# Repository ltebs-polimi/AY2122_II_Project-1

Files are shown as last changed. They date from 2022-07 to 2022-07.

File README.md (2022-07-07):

# AY2122_II_Project-1

## Pulseoximeter
The project involves the development of a portable pulseoximeter made using CY8CKIT-059 Development Kit by Cypress/Infineon and the MAX30101, a High-Sensitivity Pulse Oximeter and Heart-Rate Sensor for Wearable Health. Exploiting the circular buffer present inside the sensor, it is possible to extract the values coming from Infrared and Red LEDs and feed them inside a peak detection algorithm for PPG analysis, which outputs the SpO2 and Heart Rate values. Such function has been forked by the [MAX30101_Sensor_Library](https://github.com/sparkfun/SparkFun_MAX3010x_Sensor_Library/blob/master/src/spo2_algorithm.cpp) of the manufacturer Maxim Integrated; the function has been modified to our specific case. 
The project also involved the PCB design and production through press-n-print technique, the 3D case design and printing and the overall assembly of the final case.
## GUI
GUI_screenshot
On the GUI it is also possible to make instant changes to the registers, which directly influence the MAX30101, such as the ADC range, the LED pulse width of the two LEDs, the LEDs pulse amplitude and the Sample Rate. These values will change the Full Scale Range of the readings, as well as the SNR (signal-to-noise-ratio).
## Final assembled device
The final device resembles a commercial pulseoximeter with a rudimental hinge that secures the finger in place over the photodiode, so that a constant pressure is applied. Moreover an internal coating was applied in order not to let light pass, so to assure a reliable sensor measure.


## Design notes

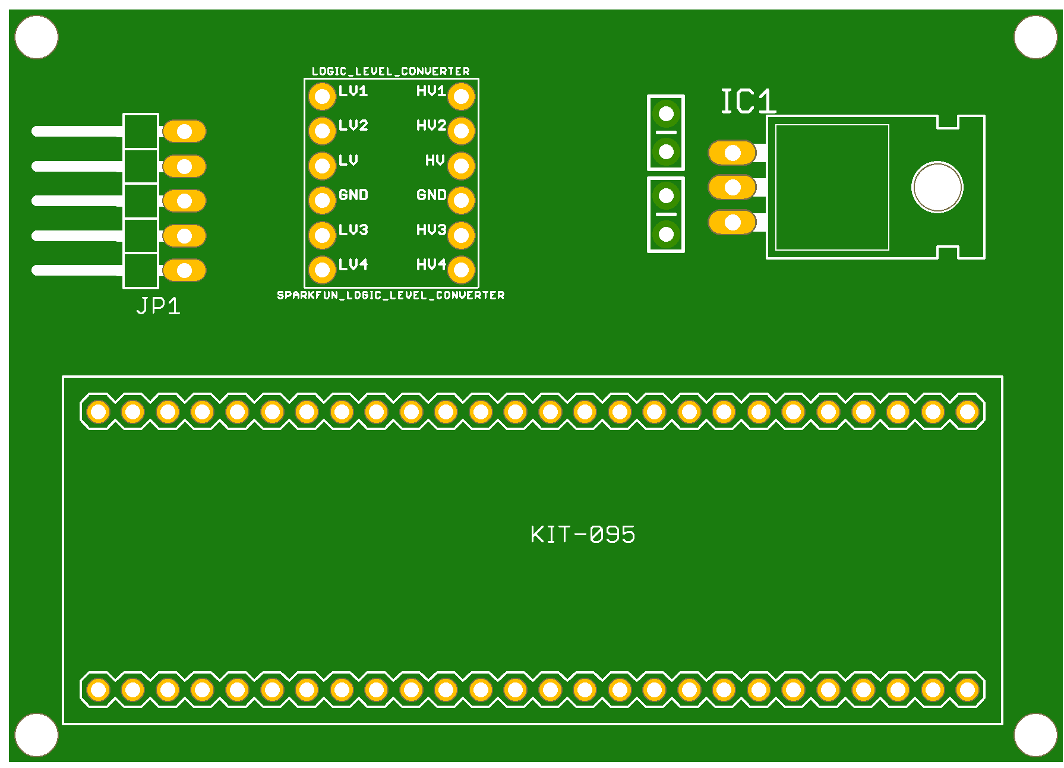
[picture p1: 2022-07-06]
EAGLE/MAX30101_Eagle/MAX30101_Qwiic_PCB_v6_top.png

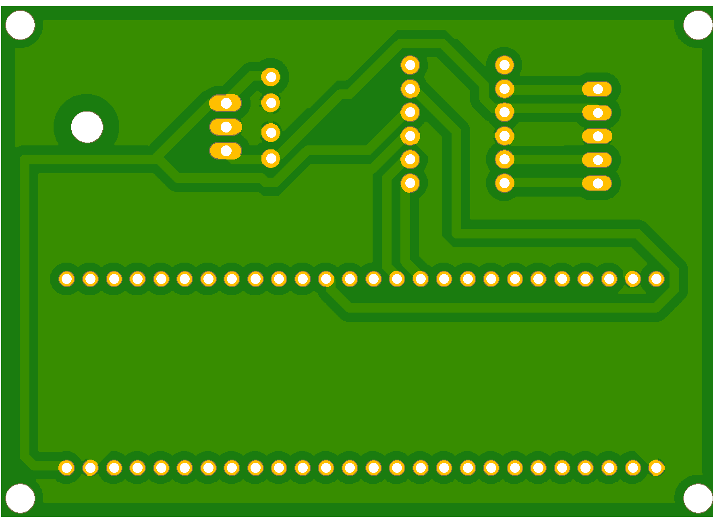
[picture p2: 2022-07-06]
EAGLE/MAX30101_Eagle/MAX30101_Qwiic_PCB_v6_bottom.png

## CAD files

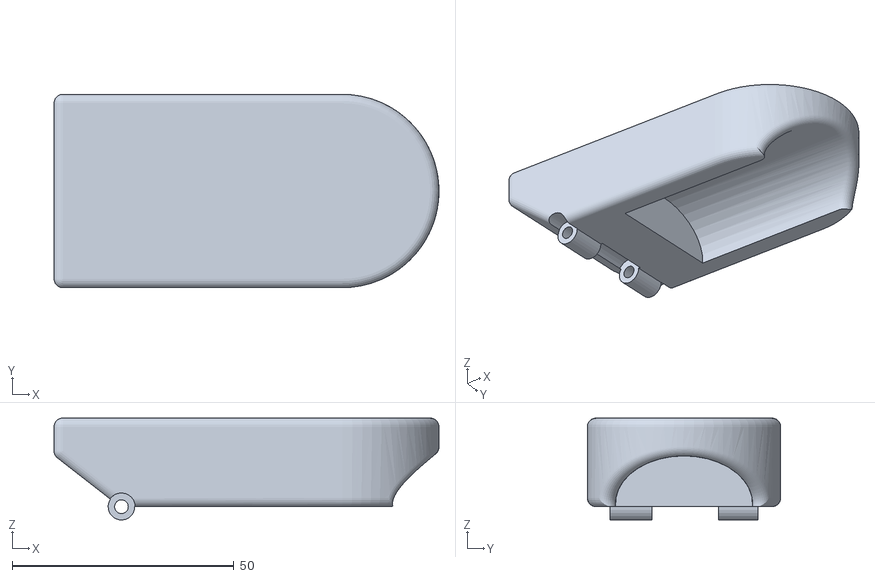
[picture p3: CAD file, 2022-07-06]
3Dcase/3Dcase_up.STL
86.8 x 43.6 x 23.0

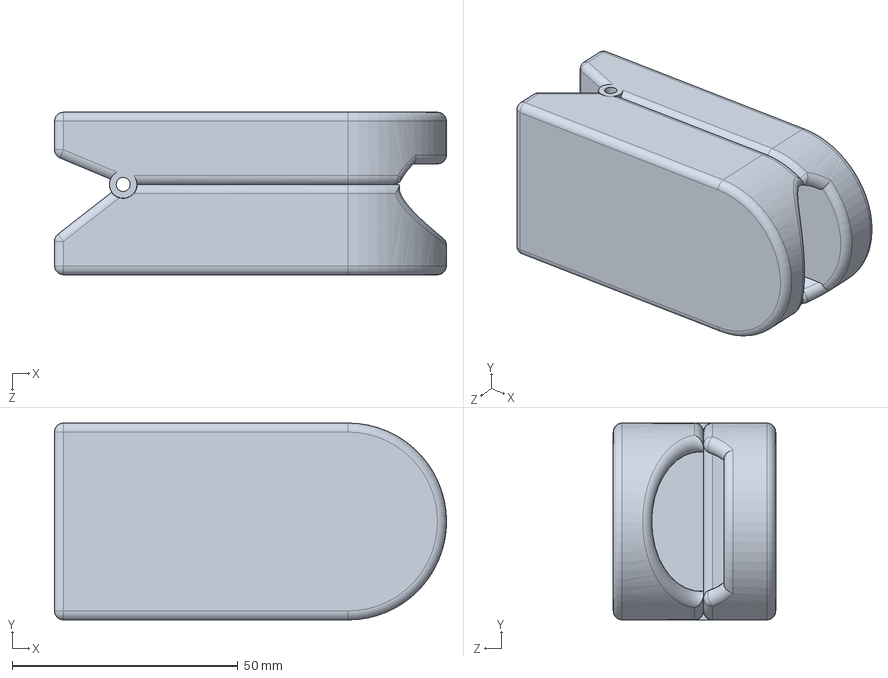
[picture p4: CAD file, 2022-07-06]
3Dcase/3Dcase.SLDPRT
86.8 x 43.6 x 36.0 mm

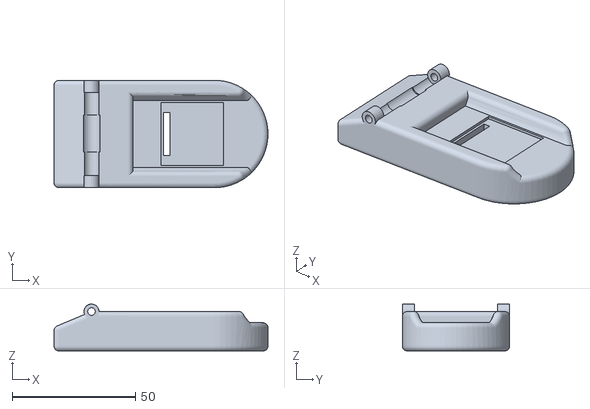
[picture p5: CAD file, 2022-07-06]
3Dcase/3Dcase_down.STL
86.8 x 43.6 x 19.0

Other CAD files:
3Dcase/3Dcase.STL

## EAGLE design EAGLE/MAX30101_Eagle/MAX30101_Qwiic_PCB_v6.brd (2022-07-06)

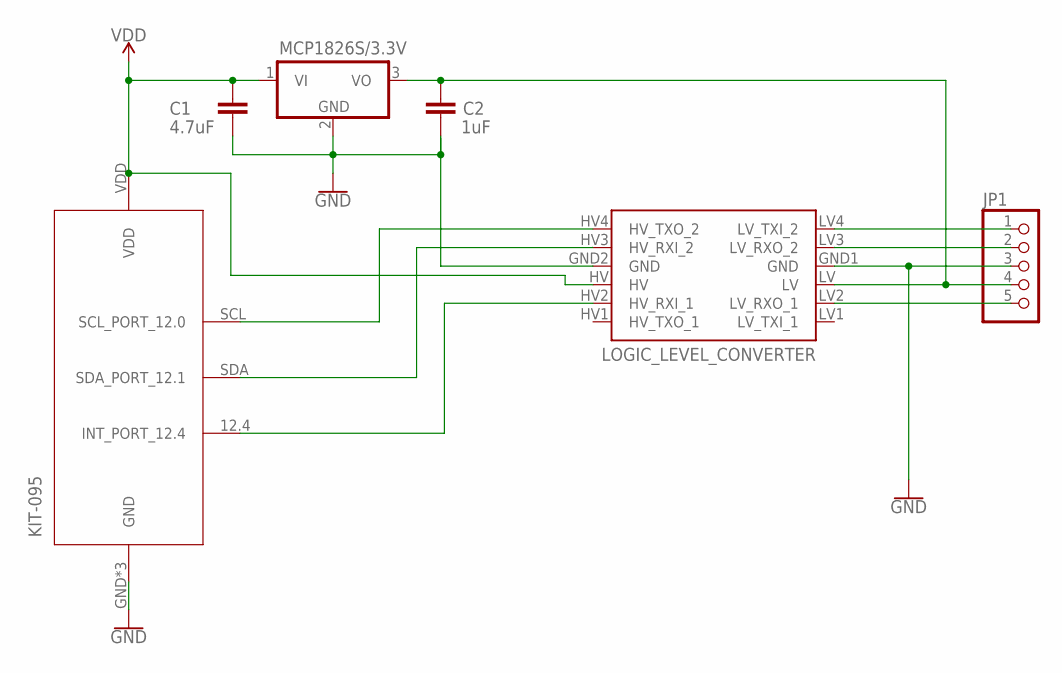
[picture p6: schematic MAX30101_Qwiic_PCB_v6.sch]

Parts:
C1: 4.7uF; CAP-PTH-SMALL-KIT
C2: 1uF; CAP-PTH-SMALL-KIT
IC1: 7805T; TO220H
JP1: PINHD-1X5/90; 1X05/90
KIT-095: KIT-095
LOGIC_LEVEL_CONVERTER: SPARKFUN_LOGIC_LEVEL_CONVERTER

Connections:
GND: C1.2, C2.2, IC1.2 (GND), JP1.3, KIT-095.GND, KIT-095.GND_ (GND), KIT-095._GND (GND), LOGIC_LEVEL_CONVERTER.GND1 (GND), LOGIC_LEVEL_CONVERTER.GND2 (GND)
unnamed: C2.1, IC1.3 (VO), JP1.4, LOGIC_LEVEL_CONVERTER.LV
unnamed: KIT-095.SCL (SCL_PORT_12.0), LOGIC_LEVEL_CONVERTER.HV4 (HV_TXO_2)
unnamed: KIT-095.SDA (SDA_PORT_12.1), LOGIC_LEVEL_CONVERTER.HV3 (HV_RXI_2)
unnamed: KIT-095.12.4 (INT_PORT_12.4), LOGIC_LEVEL_CONVERTER.HV2 (HV_RXI_1)
unnamed: JP1.1, LOGIC_LEVEL_CONVERTER.LV4 (LV_TXI_2)
unnamed: JP1.2, LOGIC_LEVEL_CONVERTER.LV3 (LV_RXO_2)
unnamed: JP1.5, LOGIC_LEVEL_CONVERTER.LV2 (LV_RXO_1)
VDD: C1.1, IC1.1 (VI), KIT-095.VDD, LOGIC_LEVEL_CONVERTER.HV

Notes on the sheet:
MCP1826S/3.3V

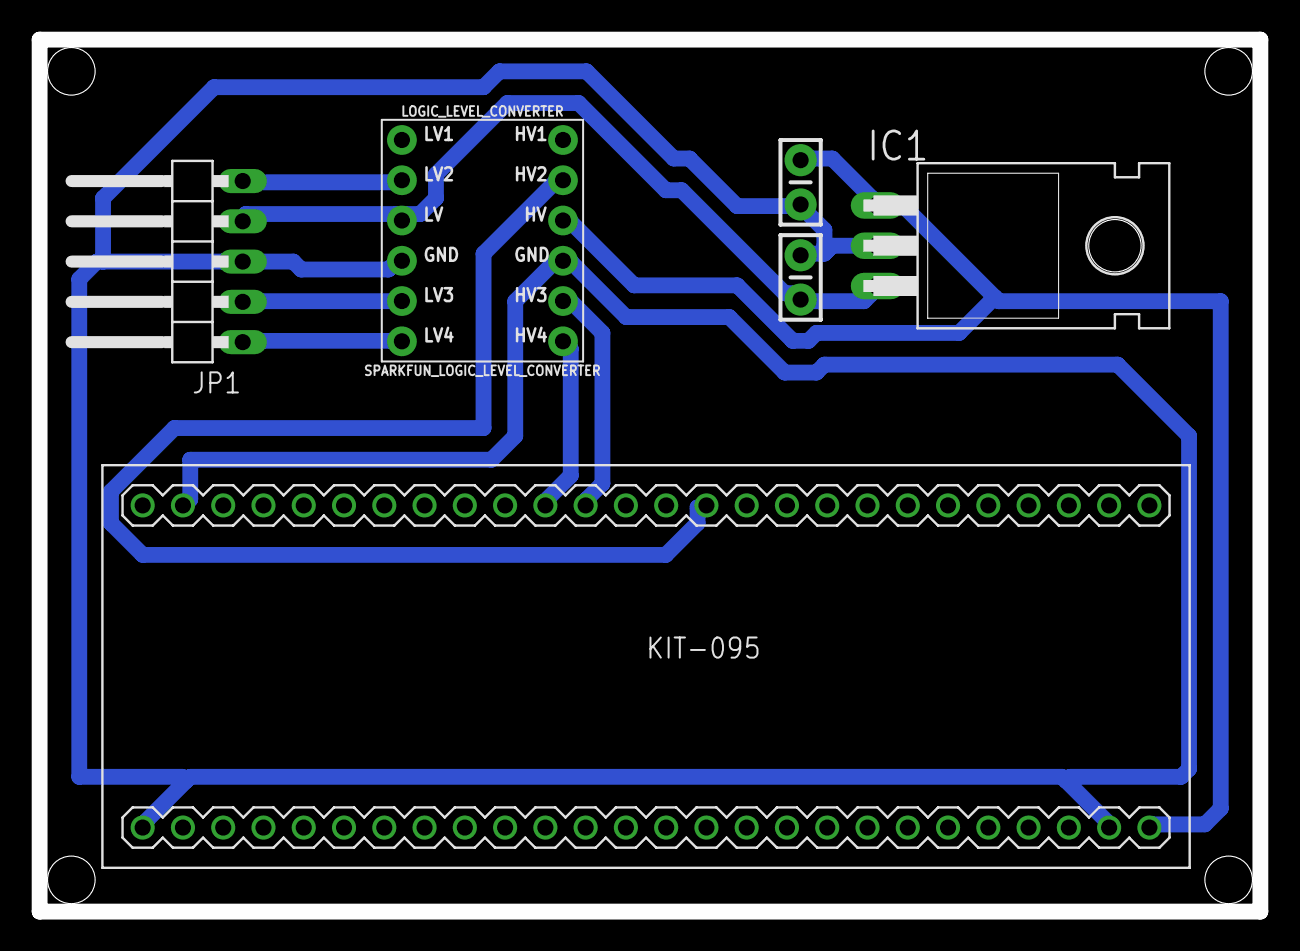
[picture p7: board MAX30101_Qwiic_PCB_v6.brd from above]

Board: 2 copper layers, 77.0 x 55.0 mm, 6 parts (0 on the bottom side), 9 nets.

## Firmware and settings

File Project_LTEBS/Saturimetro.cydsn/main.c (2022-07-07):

/*
    LAB PROJECT 2022, Group 1
    Emanuele Falli
    Federico Monterosso
    Francesca Terranova
*/

#include "project.h"
#include "MAX30101.h"
#include "stdio.h"
#include "I2C_Interface.h"
#include "SpO2_HR.h"
#include "Timer.h"
#include "isr.h"
#include "USER.h"
#include "setting_parameters.h"

#define UART_DEBUG
#define FIFO_max_size 25 
/*25 has been set as the maximum size so that half a second is measured every
time the interrupt is triggere by the filling of the FIFO*/

#ifdef UART_DEBUG
    
    #define DEBUG_TEST 1
    
#else
    
    #define DEBUG_TEST 0
    
#endif

#define debug_print(msg) do { if (DEBUG_TEST) UART_Debug_PutString(msg);} while (0)

CY_ISR_PROTO(MAX30101_ISR);

uint8_t flag_temp = 0; 
/*flag_temp is activated inside the isr code of the MAX30101 and ensures that the sampling frequency of 
the main code is executed at the desired frequency equal to that of the filling of the FIFO*/

uint8_t j=0; 
/*this flag controls the number of samples before reaching the 200 samples 
(4 seconds of measurement at a sample rate of 50 Sa/s) that trigger the actuation of the maxim function 
for spo2 and hr calculation*/
uint8 flag_start = 1;


int main(void)
{
    // Variables
    MAX30101_Data data;
    data.head = 0;
    data.tail = 0;
    char msg[50];
    uint8_t active_leds = 2;
    uint8_t rp, wp, flag = 0;
    int32_t spo2; //SPO2 value calculated through the maxim function given by the manufacturer
    int8_t validSPO2; //indicator to show if the SPO2 calculation is valid
    int32_t heartRate; //heart rate value 
    int8_t validHeartRate; //indicator to show if the heart rate calculation is valid
    uint32_t irBuffer[200]; //infrared LED sensor data
    uint32_t redBuffer[200];  //red LED sensor data
    int32_t bufferLength = 200;
    int32_t somma=0; 
    int32_t avg_hr=0;
    int num_samples;
 
    int i=0;
    int f=1;
    
    // Initialization
    MAX30101_Start();
    UART_Debug_Start();
    CyDelay(100);    
    if (MAX30101_IsDevicePresent() == MAX30101_OK)
    {
        // Check if device is present
        Connection_LED_Write(1);
        
        // Soft reset sensor
        MAX30101_Reset();
        CyDelay(100);
       
        // Wake up sensor
        MAX30101_WakeUp();       
        // Only the FIFO_AFULL interrupt is activated, therefore the isr code works only in this case.
        MAX30101_EnableFIFOAFullInt();
     
        // set 25 samples to trigger interrupt
        MAX30101_SetFIFOAlmostFull(FIFO_max_size);

        // enable fifo rollover
        MAX30101_EnableFIFORollover();
        
        // samples averaged       
        MAX30101_SetSampleAverage(MAX30101_SAMPLE_AVG_2);
        // Set LED Power level
        MAX30101_SetLEDPulseAmplitude(MAX30101_LED_1, 0x1F);        
        MAX30101_SetLEDPulseAmplitude(MAX30101_LED_2, 0x1F);
               
        // Set ADC Range
        MAX30101_SetSpO2ADCRange(MAX30101_ADC_RANGE_8192);
        
        // Pulse width
        MAX30101_SetSpO2PulseWidth(MAX30101_PULSEWIDTH_411);
        
        /* Set Sample Rate, in a way to ensure that 50 Sa/s is always kept constant, therefore the 
        sample average needs to be configured properly when changing the sample rate through the GUI*/ 
        MAX30101_SetSpO2SampleRate(MAX30101_SAMPLE_RATE_100);
        
        // Set mode (always spo2 mode in this project)
        MAX30101_SetMode(MAX30101_SPO2_MODE);
        
        // Enable Slots
        MAX30101_DisableSlots();
        
    }
    
    isr_MAX30101_StartEx(MAX30101_ISR);
    isr_RX_StartEx(Custom_ISR_RX);
    
    // Clear FIFO
    MAX30101_ClearFIFO();
    
    CyGlobalIntEnable; /* Enable global interrupts. */
      
    for(;;)
    {    
        if(flag_temp == 1)
        /*this flag is controlled by the isr of the MAX (issued only by the filling of the FIFO because
        the other interrupts are all disabled*/
        {
            MAX30101_IsFIFOAFull(&flag);
            if(flag>0)
            {
                MAX30101_ReadReadPointer(&rp);
                MAX30101_ReadWritePointer(&wp);
                //Calculate the number of readings we need to get from sensor (always 25 in this case)
                num_samples = wp - rp;
                if (num_samples <= 0) num_samples += 32; //Wrap condition                
                // Read FIFO
                MAX30101_ReadFIFO(num_samples, active_leds, &data);
                for (i=0;i<num_samples;i++)
                {                    
                    //the 25 samples are stored separately inside two buffers of length 200
                    redBuffer[j] = data.red[data.tail+i];
                    irBuffer[j] = data.IR[data.tail+i];
                    j++;
                    debug_print("1,");
                    /*these numbers help us in intercepting the right value inside the python code,
                    so that they are placed in the corresponding array accordingly and are displayed
                    inside the plot or saved in the labels of Spo2 and HR*/
                    sprintf(msg, "%ld,", data.IR[data.tail+i]);
                    debug_print(msg);
                    debug_print("2,");
                    sprintf(msg, "%ld,", data.red[data.tail+i]);
                    debug_print(msg);
                    
                    if(j<bufferLength)
                    {
                        /*these null values ensure that the array length sent via UART to the GUI 
                        is always constant; in this way when, after the iterations, we obtain a measure
                        of Spo2 and HR, we can save them appropriately.*/
                        debug_print("0,");
                        debug_print("0,");
                        debug_print("0,");
                        debug_print("0\n");
                    }
                }
                
                if(j>=bufferLength) 
                {
                    //we have reached 200 samples and the maxim function is triggered
                    maxim_heart_rate_and_oxygen_saturation(irBuffer, bufferLength, redBuffer, &spo2, &validSPO2, &heartRate, &validHeartRate);
                    j=bufferLength - 50;
                    /*50 samples are deleted, and replaced with a new second of measurement
                    coming from the sensor*/
                    for (int i=50; i<bufferLength; i++) 
                    {
                        /*The remaining 150 samples are shifter up at the beginning of the array so 
                        that the last second is entered at the end and the appropriate sequence is kept.*/
                        redBuffer[i-50] = redBuffer[i];
                        irBuffer[i-50] = irBuffer[i];
                    }
                    /*the spo2 and HR values are generated and will replace the empty values shown before,
                    to be sent via UART to the GUI*/
                    debug_print("3,");
                    sprintf(msg, "%ld,", spo2);
                    debug_print(msg);
                    debug_print("4,");
                    sprintf(msg, "%ld\n", avg_hr);
                    debug_print(msg);
                    if(heartRate > 60 && heartRate < 120) 
                    {
                        //an average of 10 values of HR is performed to obtain a more constant value
                        somma += heartRate;
                        if(f==10)
                        {
                            somma = somma/10;
                            f = 0;
                            avg_hr = somma;
                            somma = 0;
                        }
                        f++;
                    }
                }
            }
            
            if(flag_ADC == 1)
            {
                /*this series of flags represent each parameter that can be changed via the GUI, each
                flag is activated when changing a specific parameter and the setting parameters function
                is performed.*/
                if(flag_start)
                {
                    /*the flag_start is activated the first time the code is run, after the user activates a changing of a
                    parameter inside the GUI; it is done in a way to ensure that all the other parameters not changed
                    are still initialized to a default variable, otherwise the program would not function anymore.*/
                    Pulse_amp = 0x1F;
                    Pulse_width = MAX30101_PULSEWIDTH_411;
                    Samples = MAX30101_SAMPLE_RATE_100;
                    Average = MAX30101_SAMPLE_AVG_2;
                    flag_start = 0;
                }
                setting_parameters(ADC_range, Pulse_width, Pulse_amp, Samples, Average);
                flag_ADC = 0;
                
            }
            
            if(flag_PW == 1)
            {
                if(flag_start)
                {
                    Pulse_amp = 0x1F;
                    Samples = MAX30101_SAMPLE_RATE_100;
                    Average = MAX30101_SAMPLE_AVG_2;
                    ADC_range = MAX30101_ADC_RANGE_4096;
                    flag_start = 0;
                }
                setting_parameters(ADC_range, Pulse_width,  Pulse_amp, Samples, Average);
                flag_PW = 0;
            }
            
            if(flag_PA == 1)
            {
                if(flag_start)
                {
                    Pulse_width = MAX30101_PULSEWIDTH_411;
                    Samples = MAX30101_SAMPLE_RATE_100;
                    Average = MAX30101_SAMPLE_AVG_2;
                    ADC_range = MAX30101_ADC_RANGE_4096;
                    flag_start = 0;
                }
                setting_parameters(ADC_range, Pulse_width,  Pulse_amp, Samples, Average);
                flag_PA = 0;
            }
            
            if(flag_SR == 1)
            {
                if(flag_start)
                {
                    Pulse_width = MAX30101_PULSEWIDTH_411;
                    Pulse_amp = 0x1F;
                    ADC_range = MAX30101_ADC_RANGE_4096;
                    flag_start = 0;
                }
                setting_parameters(ADC_range, Pulse_width,  Pulse_amp, Samples, Average);
                flag_SR = 0;
            }
            flag_temp = 0;
        }        
    } 
}   


CY_ISR(MAX30101_ISR)
{
    flag_temp = 1;
    Connection_LED_Write(!Connection_LED_Read());
    MAX30101_INT_ClearInterrupt();
}

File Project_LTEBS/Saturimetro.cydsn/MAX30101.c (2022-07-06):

/**
*   Source file for the MAX30101 library.
*/

#include "I2C_Interface.h"
#include "I2C_Master.h"
#include "MAX30101.h"
#include "string.h"
#include "stdio.h"
#include "project.h"
#include "isr.h"

//==============================================
//          MACROS
//==============================================

/**
*   \brief Mask for Power Ready interrupt.
*/
#define MAX30101_INT_PWR_RDY_MASK   0xFE

/**
*   \brief Mask for FIFO A FULL interrupt.
*/
#define MAX30101_INT_FIFO_A_FULL_MASK   0x7F

/**
*   \brief Enable FIFO A FULL interrupt.
*/
#define MAX30101_INT_FIFO_A_FULL_ENABLE 0x80

/**
*   \brief Disable FIFO A FULL interrupt.
*/
#define MAX30101_INT_FIFO_A_FULL_DISABLE 0x00

/**
*   \brief Mask for PPG ready interrupt.
*/
#define MAX30101_INT_PPG_RDY_MASK     0xBF

/**
*   \brief Enable PPG ready interrupt.
*/
#define MAX30101_INT_PPG_RDY_ENABLE 0x40

/**
*   \brief Disable PPG ready interrupt.
*/
#define MAX30101_INT_PPG_RDY_DISABLE 0x00

/**
*   \brief Mask for FIFO overflow interrupt.
*/
#define MAX30101_INT_ALC_OVF_MASK     0xDF

/**
*   \brief Enable OVERFLOW interrupt.
*/
#define MAX30101_INT_ALC_OVF_ENABLE 0x20

/**
*   \brief Disable OVERFLOW interrupt.
*/
#define MAX30101_INT_ALC_OVF_DISABLE 0x00

/**
*   \brief Mask for temperature data ready interrupt.
*/
#define MAX30101_INT_TMP_RDY_MASK     0xFD

/**
*   \brief Enable temperature ready interrupt.
*/
#define MAX30101_INT_TMP_RDY_ENABLE 0x02

/**
*   \brief Disable temperature ready interrupt.
*/
#define MAX30101_INT_TMP_RDY_DISABLE 0x00

/**
*   \brief Mask for sample average settings.
*/
#define MAX30101_SMP_AVG_MASK    0x1F

/**
*   \brief Mask for fifo rollover.
*/
#define MAX30101_FIFO_ROLLOVER_MASK    0xEF

/**
*   \brief Mask for sample average settings.
*/
#define MAX30101_FIFO_ROLLOVER_ENABLE    0x10

/**
*   \brief Mask for sample average settings.
*/
#define MAX30101_FIFO_ROLLOVER_DISABLE    0x00

/**
*   \brief Mask for FIFO A Full samples.
*/
#define MAX30101_FIFO_A_FULL_MASK   0xF0

/**
*   \brief Mask for shutdown bit.
*/
#define MAX30101_SHUTDOWN_MASK 0x7F

/**
*   \brief Enable shutdown
*/
#define MAX30101_SHUTDOWN_ENABLE 0x80

/**
*   \brief Disable shutdown.
*/
#define MAX30101_SHUTDOWN_DISABLE 0x00

/**
*   \brief Reset bit mask.
*/
#define MAX30101_RESET_MASK 0xBF

/**
*   \brief Set reset bit.
*/
#define MAX30101_RESET_ENABLE 0x40

/**
*   \brief Mode mask.
*/
#define MAX30101_MODE_MASK 0xF8

/**
*   \brief SPO2 ADC Range mask.
*/
#define MAX30101_SPO2_ADC_RANGE_MASK 0x9F 

/**
*   \brief SPO2 Sample Rate mask.
*/
#define MAX30101_SPO2_SAMPLE_RATE_MASK 0xE3

/**
*   \brief SPO2 Sample Rate mask.
*/
#define MAX30101_SPO2_PULSEWIDTH_MASK 0xFC

/**
*   \brief Multi-LED SLOT1 mask.
*/
#define MAX30101_SLOT1_MASK  		0xF8

/**
*   \brief Multi-LED SLOT2 mask.
*/
#define MAX30101_SLOT2_MASK  		0x8F

/**
*   \brief Multi-LED SLOT3 mask.
*/
#define MAX30101_SLOT3_MASK  		0xF8

/**
*   \brief Multi-LED SLOT4 mask.
*/
#define MAX30101_SLOT4_MASK  		0x8F

#define MAX30101_SHIFT(resolution) 4-resolution

//==============================================
//          FUNCTION PROTOTYPESS
//==============================================

static uint8_t MAX30101_BitMask(uint8_t reg_addr, uint8_t mask, uint8_t thing);

static uint8_t MAX30101_WriteRegister(uint8_t reg_addr, uint8_t reg_data);


// Start the device
uint8_t MAX30101_Start(void)
{
    I2C_Peripheral_Start();
    return MAX30101_Reset();
}

// Check if device is present on I2C bus
uint8_t MAX30101_IsDevicePresent(void)
{
    if (I2C_Peripheral_IsDeviceConnected(MAX30101_I2C_ADDRESS) == I2C_NO_ERROR)
    {
        return MAX30101_OK;
    }
    
    return MAX30101_DEV_NOT_FOUND;
}

//==============================================
//          INTERRUPT RELATED FUNCTIONS
//==============================================

// Check interrupt status
uint8_t MAX30101_IsFIFOAFull(uint8_t* flag)
{
    // Read register
    uint8_t temp;
    uint8_t error = MAX30101_ReadRegister(MAX30101_INT_ST_1, &temp);
    *flag = temp & (~MAX30101_INT_FIFO_A_FULL_MASK);
    return error;
}

uint8_t MAX30101_IsPPGReady(uint8_t* flag)
{
    // Read register
    uint8_t temp;
    uint8_t error = MAX30101_ReadRegister(MAX30101_INT_ST_1, &temp);
    *flag = temp & (~MAX30101_INT_PPG_RDY_MASK);
    return error;
}
uint8_t MAX30101_IsALCOverflow(uint8_t* flag)
{
    // Read register
    uint8_t temp;
    uint8_t error = MAX30101_ReadRegister(MAX30101_INT_ST_1, &temp);
    *flag = temp & (~MAX30101_INT_ALC_OVF_MASK);
    return error;
}
uint8_t MAX30101_IsPowerReady(uint8_t* flag)
{
    // Read register
    uint8_t temp;
    uint8_t error = MAX30101_ReadRegister(MAX30101_INT_ST_1, &temp);
    *flag = temp & (~MAX30101_INT_PWR_RDY_MASK);
    return error;
}
uint8_t MAX30101_IsTempReady(uint8_t* flag)
{
    // Read register
    uint8_t temp;
    uint8_t error = MAX30101_ReadRegister(MAX30101_INT_ST_2, &temp);
    *flag = temp & (~MAX30101_INT_TMP_RDY_MASK);
    return error;
}
    
// Enable interrupts
uint8_t MAX30101_EnableFIFOAFullInt(void)
{
    return MAX30101_BitMask(MAX30101_INT_EN_1, MAX30101_FIFO_A_FULL_MASK, MAX30101_INT_FIFO_A_FULL_ENABLE);
}
uint8_t MAX30101_EnablePPGReadyInt(void)
{
    return MAX30101_BitMask(MAX30101_INT_EN_1, MAX30101_INT_PPG_RDY_MASK, MAX30101_INT_PPG_RDY_ENABLE);
}
uint8_t MAX30101_EnableALCOverflowInt(void)
{
    return MAX30101_BitMask(MAX30101_INT_EN_1, MAX30101_INT_ALC_OVF_MASK, MAX30101_INT_ALC_OVF_ENABLE);
}

uint8_t MAX30101_EnableTempReadyInt(void)
{
    return MAX30101_BitMask(MAX30101_INT_EN_2, MAX30101_INT_TMP_RDY_MASK, MAX30101_INT_TMP_RDY_ENABLE);
}

// Disable interrupts
uint8_t MAX30101_DisableFIFOAFullInt(void)
{
    return MAX30101_BitMask(MAX30101_INT_EN_1, MAX30101_FIFO_A_FULL_MASK, MAX30101_INT_FIFO_A_FULL_DISABLE);
}

uint8_t MAX30101_DisablePPGReadyInt(void)
{
    return MAX30101_BitMask(MAX30101_INT_EN_1, MAX30101_INT_PPG_RDY_MASK, MAX30101_INT_PPG_RDY_DISABLE);
}

uint8_t MAX30101_DisableALCOverflowInt(void)
{
    return MAX30101_BitMask(MAX30101_INT_EN_1, MAX30101_INT_ALC_OVF_MASK, MAX30101_INT_ALC_OVF_DISABLE);
}

uint8_t MAX30101_DisableTempReadyInt(void)
{
    return MAX30101_BitMask(MAX30101_INT_EN_1, MAX30101_INT_TMP_RDY_MASK, MAX30101_INT_TMP_RDY_DISABLE);
}

//==============================================
//          FIFO FUNCTIONS
//==============================================
// Read Write pointer
uint8_t MAX30101_ReadWritePointer(uint8_t* wr)
{
    return MAX30101_ReadRegister(MAX30101_FIFO_WP, wr);
}

// Read Overflow counter
uint8_t MAX30101_ReadOverflowCounter(uint8_t* oc)
{
    return MAX30101_ReadRegister(MAX30101_FIFO_OVF_CNT, oc);
}

// Read Read Pointer
uint8_t MAX30101_ReadReadPointer(uint8_t* rr)
{
    return MAX30101_ReadRegister(MAX30101_FIFO_RP, rr);
}
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

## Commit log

2022-07-06 merging spo2_new_function into master
    [Saturimetro.sdf]
2022-07-06 Final GUI
    [Saturimetro.sdf]
2022-07-06 deleted some files not needed
    [pulse_chiusura.SLDPRT, pulse_chiusura_step2.SLDPRT, pulse_v2.SLDPRT]

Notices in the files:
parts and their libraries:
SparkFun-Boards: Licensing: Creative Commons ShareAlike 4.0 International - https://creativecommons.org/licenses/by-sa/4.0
